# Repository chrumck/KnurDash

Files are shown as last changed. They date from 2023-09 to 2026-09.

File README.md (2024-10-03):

# KnurDash - Racing Data Logger with [RaceChrono](https://racechrono.com/) Integration

<p align="center">
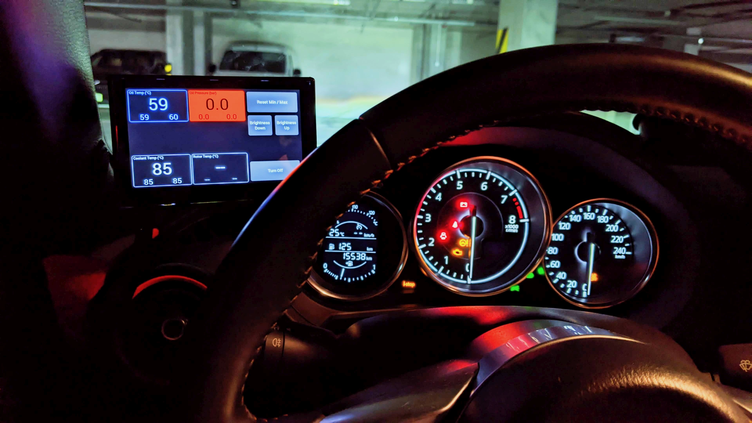
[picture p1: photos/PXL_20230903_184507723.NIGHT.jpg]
    
</p>

## Description

A racing logger for an ND2 Mazda MX-5, integrating wide ranging functionality into one unit:

- Reading analog sensors (oil pressure and temperature, rotor temperature)
- Reading CANBUS data (coolant and intake temperature, RPM, etc.)
- Displaying data in a clear and aesthetically pleasing way
- Making data available via Bluetooth as [RaceChrono DIY BLE device](https://github.com/aollin/racechrono-ble-diy-device)

---

## Technical Details

The system has two main components, the display unit and the sensor unit. The communication between the two is executed through I2C protocol (1.2m cable is pushing it though. With careful cable prep I still get ~0.5% error rate on comms.). The display unit is made of a Raspberry Pi 4B board and a [4.3 inch touchscreen](https://www.waveshare.com/4.3inch-dsi-lcd-with-case.htm). The sensor unit houses a [5V power supply](https://www.pololu.com/product/3782/specs), two [4-channel ADC's](https://www.dfrobot.com/index.php?route=product/product&product_id=1182&search=DFR0316), a [motion tracking device](https://www.dfrobot.com/index.php?route=product/product&product_id=880), and a [Longan Labs I2C CAN Controller](https://docs.longan-labs.cc/1030017/) with a [custom firmware](https://github.com/chrumck/I2C_CAN_Firmware) built specifically for this project.

Additionally, the sensor unit contains circuitry [(LTSpice schematic)](./LTSpice/PowerOffCircuit.asc) allowing starting the system when the vehicle's START button is pressed. This has been accomplished by pulling RPI's GLOBAL_EN to ground when RPI is off. When RPI is running and [3.3V is on](https://www.raspberrypi.com/documentation/computers/raspberry-pi.html#POWER_OFF_ON_HALT), the starting circuit is disabled to prevent hard resets while RPI system and the OS is running.

Bluetooth communication was implemented using the [bluez_inc](https://github.com/weliem/bluez_inc) library (kudos to [weliem](https://github.com/weliem) for making my life easier!). The system implements the [RaceChrono BLE DIY](https://github.com/aollin/racechrono-ble-diy-device) protocol. The system works as a pass-through for selected CAN frames. Additionally, all analog data collected by the unit is exposed as an additional CAN frame and made available to RaceChrono for logging.

The display unit has a buzzer installed. The buzzer is turned on when the oil pressure drops below a certain threshold and the RPM is above idling.

The rotor temperature is measured with an industrial grade 0~1000 degC infrared pyrometer with a 4-20mA output.

As of 2023-09-04, the system is installed in the car and in initial testing . The transmission, differential, and rotor temperature sensors were not installed yet, but coming soon!

Future development:

- Read motion tracking data from the already installed unit and expose it to RaceChrono
- Add a [differential GPS](https://www.sparkfun.com/products/15136) board

---

## Pictures

### Display Unit

 <p align="center">
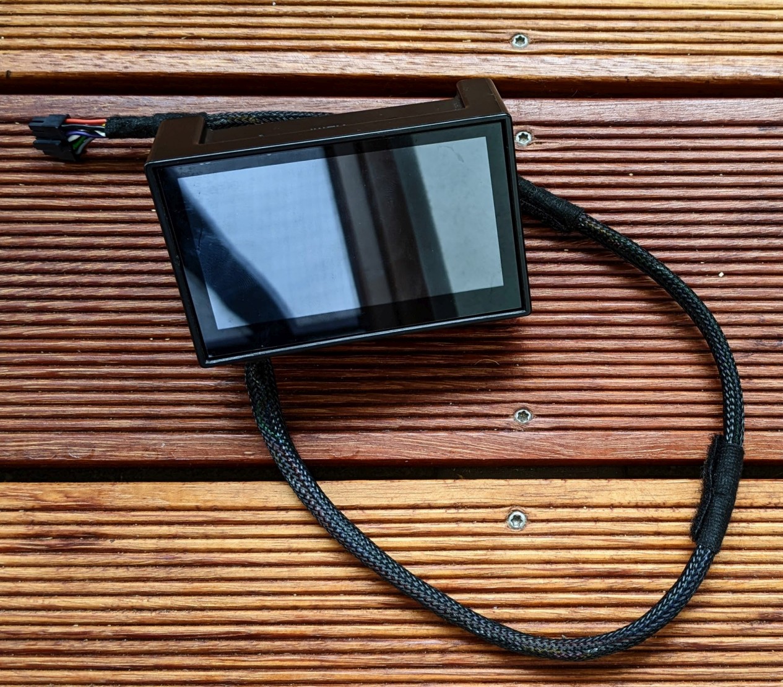
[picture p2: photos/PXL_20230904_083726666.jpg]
    
 
</p>
 <p align="center">
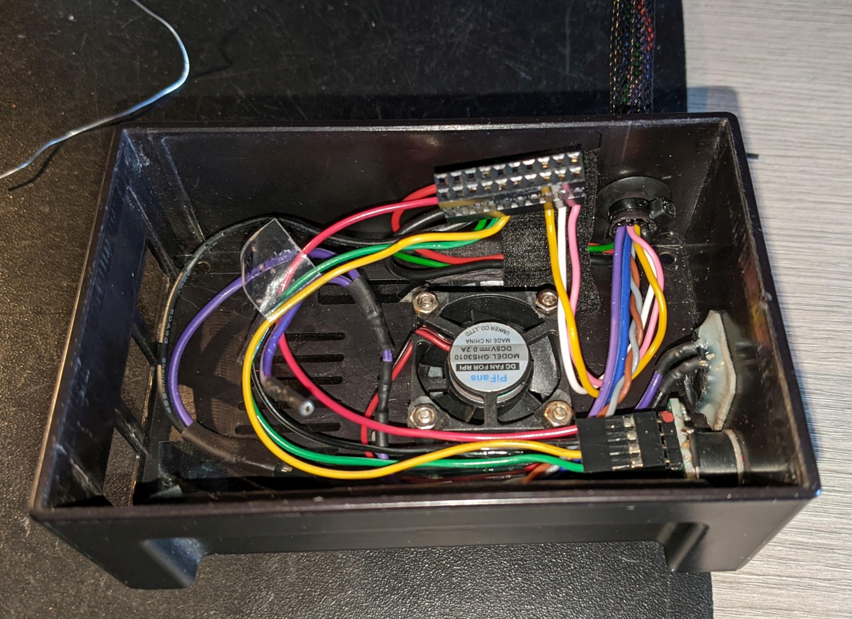
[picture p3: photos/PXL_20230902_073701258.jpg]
    
 </p>

### Sensor Unit

<p align="center">
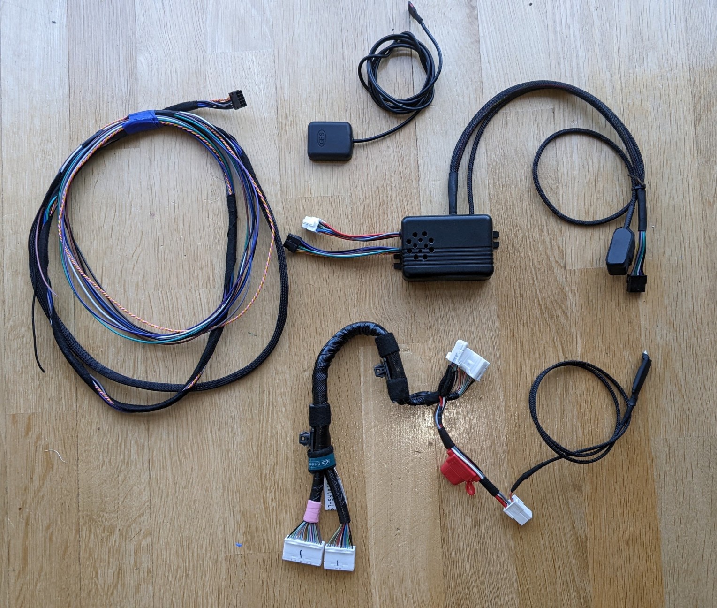
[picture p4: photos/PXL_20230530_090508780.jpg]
    
 </p>

<p align="center">
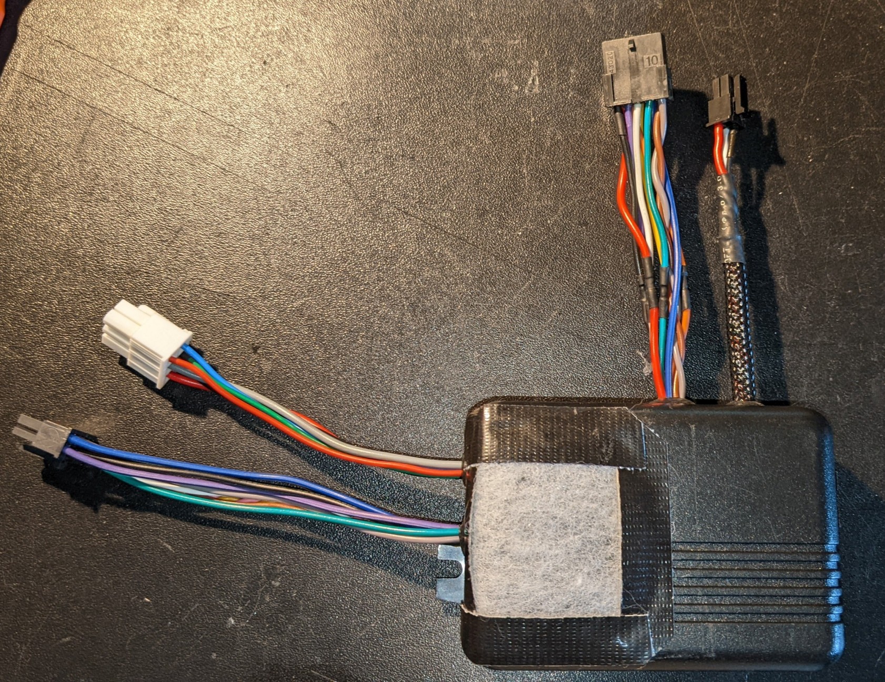
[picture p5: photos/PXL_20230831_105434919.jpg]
    
 </p>

 <p align="center">
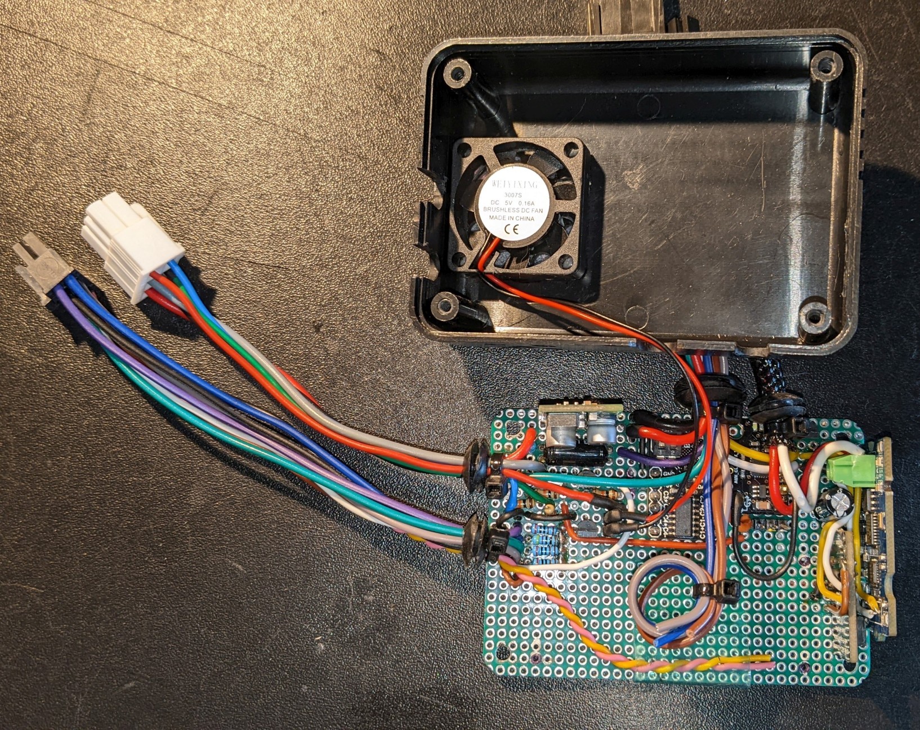
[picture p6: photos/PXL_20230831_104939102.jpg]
    
 </p>

  <p align="center">
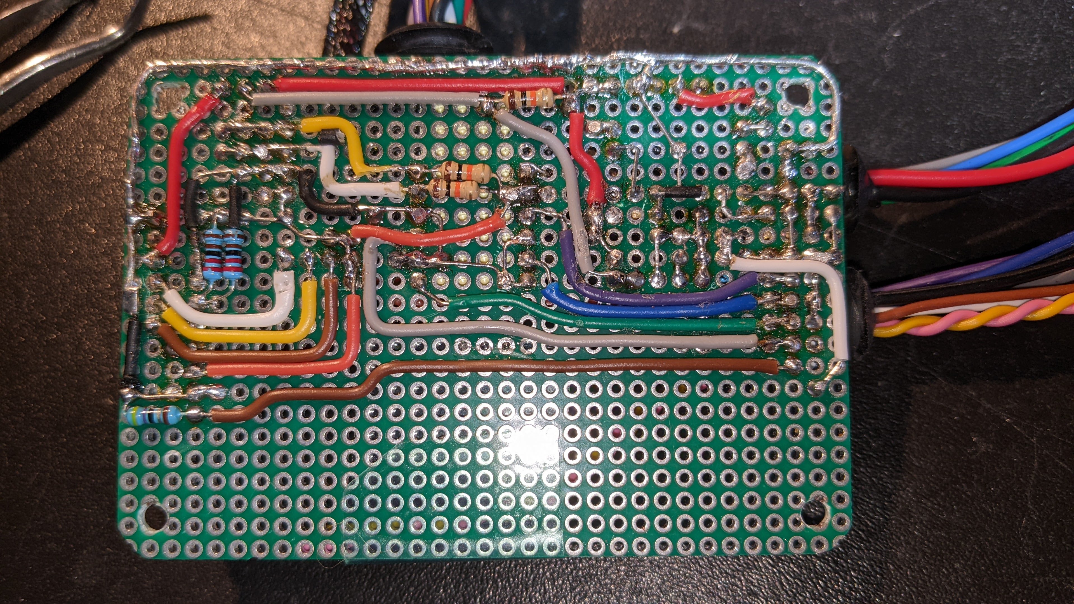
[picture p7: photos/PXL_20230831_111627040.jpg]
    
 </p>

### Sensors

 <p align="center">
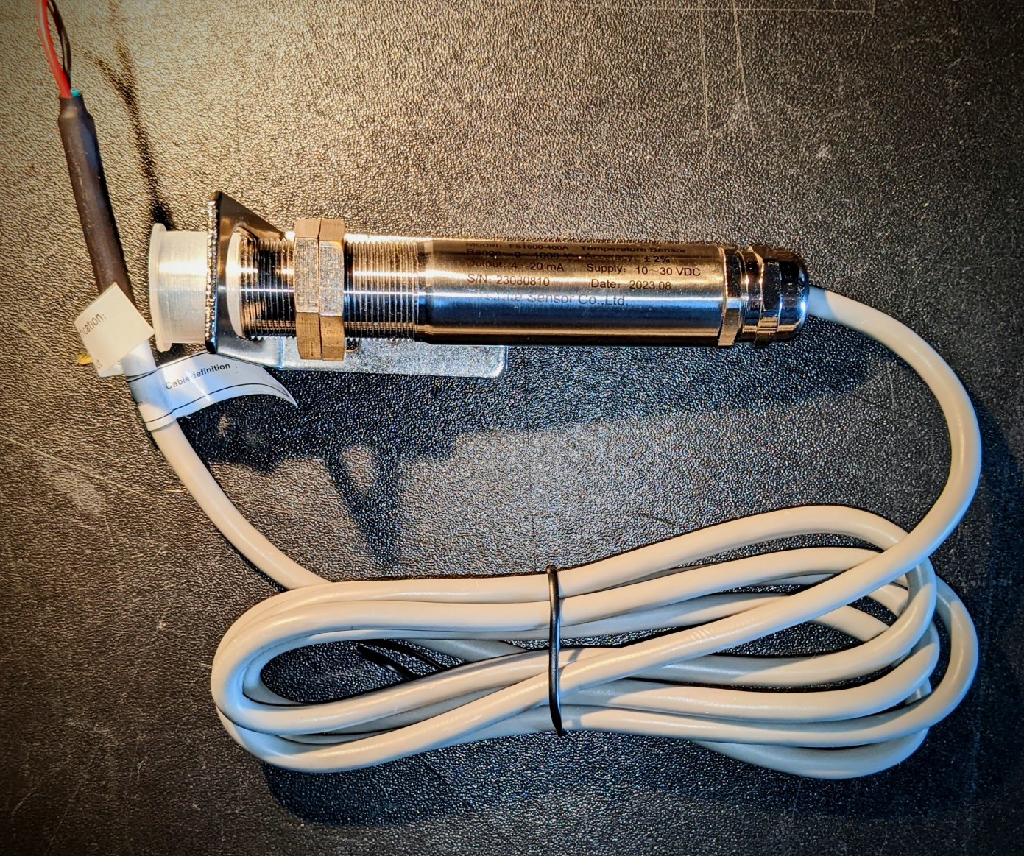
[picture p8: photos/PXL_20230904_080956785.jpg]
    
 </p>

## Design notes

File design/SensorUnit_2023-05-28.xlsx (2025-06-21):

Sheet: Calcs
Vref 3V
Vdd | 3.3 | V
Vref 3V | 3 | V
Rstab | 220 | Ohm
I | 1.363636364
P | 0.0004090909091 | W
Sensors
Vin | 3.3 | V
Rref | 20000 | Ohm
Rsensor | 124 | Ohm
Vout | 20.3 | mV | 40.66785927
I
 | Ref | min | max | Imin mA | Imax mA | vmin V | vmax V | vmin mV | vmax mV | Pmax (W) | Rmin | Rmax
Temp | 2000 | 20 | 2500 | 1.63 | 0.73 | 0.03 | 1.83 | 32.67326733 | 1833.333333 | 0.002 | 2020 | 4500 | 0.0009900990099 | 1010
Pressure | 465 | 8 | 200 | 6.98 | 4.96 | 0.06 | 0.99 | 55.81395349 | 992.481203 | 0.016 | 473 | 665 | 0.00422832981 | 236.5 | 0.00521842882 | 191.62856
Brake Caliper T | 20000 | 122 | 32000 | 0.16 | 0.06 | 0.02 | 2.03 | 20.0079515 | 2030.769231 | 0.0002094230769 | 20122 | 52000 | 9.939369844e-05 | 10061
Vsensor | 162 | mV |  | Capacitor discharge speed
Vref | 3138 | mV |  | uF | ohm | v1 | v0 | t | tms | tus
Rref | 2000 | Ohm |  | 470 | 500 | 3.3 | 3.31
I | 1.569 | mA |  | 0.00047 | 500 | 3.3 | 3.31 | -0.0007110444154 | -0.7110444154 | -711.0444154
Rsensor | 103.250478 | Ohm
Tsensor | 100.1 | degC
Press | 2.7 | bar
IR Rotor Temp Sensor
I_mA | Rref_Ohm | mV
4 | 47 | 188
20 | 47 | 940
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

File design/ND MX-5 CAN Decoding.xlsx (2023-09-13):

Notes: * All bytes are big-endian. |  |  | verified on 2019 ND2 AE
 |  |  | A | B | C | D | E | F | G | H
 | Offset |  | 0 | 1 | 2 | 3 | 4 | 5 | 6 | 7
BUS | CAN ID (HEX) | CAN ID (DEC) | Byte 1 | Byte 2 | Byte 3 | Byte 4 | Byte 5 | Byte 6 | Byte 7 | Byte 8
HS CAN | 202 | 514 | RPM Scaling: 0.25 |  | VehicleSpeed KPH Scaling: 0.01 |  | Throttle % Scaling: 0.4
HS CAN | 165 | 357 |  |  | Clutch_Neutral Neutral: 22 (dec) Clutch-in: 25 (dec) Clutch-out: 23 (dec) |  |  |  | CurrentGear Neutral/1st: 19 (dec) 2nd: 11(dec) 3rd: 7 (dec) 4th: 6 (dec) 5th: 5 (dec)
HS CAN | 240 | 576 | Steering Torque [unitless] offset: -32512, scaling: 1
HS CAN | 78 | 120 |  |  |  | BrakePressure [unitless] Scaling: 1 Offset: -152 starting bit: 28, length 12
HS CAN | 215 | 533 | Wheel1_Speed KPH Scale: 0.01, Offset: -100 |  | Wheel2_Speed KPH Scale: 0.01, Offset: -100 |  | Wheel3_Speed KPH Scale: 0.01, Offset: -100 |  | Wheel4_Speed KPH Scale: 0.01, Offset: -100
HS CAN | 86 | 134 | Steering scaling: -0.0228, offset: 365
HS CAN | 420 | 1056 | EngCoolantTemp offset: -40
HS CAN | 4FA | 1274 |  |  |  |  | IntakeAirTemp C offset: -40
CAN mapping for Auto Sport Labs RaceCapture
 |  |  | Download link for RaceCaptureSettings (https://drive.google.com/open?id=15iy2YZ649EJ6RIQSPAJwfBqKBYgafXnz) |  |  |  | https://github.com/timurrrr/RaceChronoDiyBleDevice/blob/master/can_db/mazda_mx5_nd.md

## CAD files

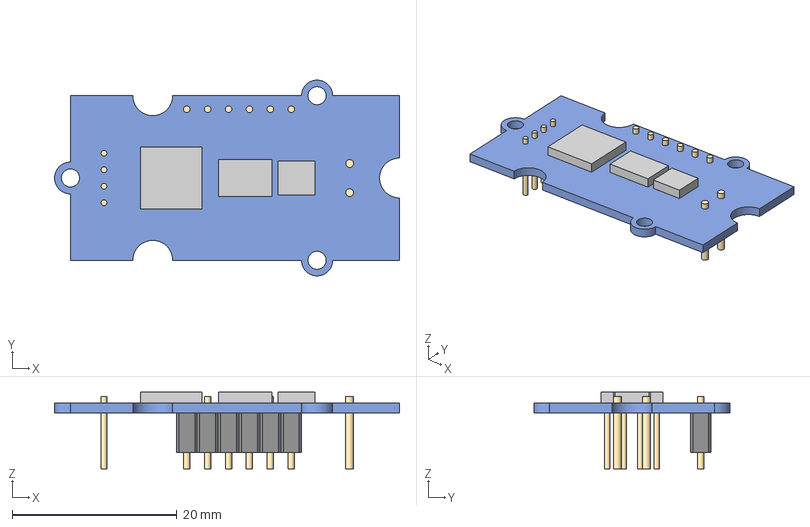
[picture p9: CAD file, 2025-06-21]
KiCAD/Longan_I2C_CAN/Longan_I2C_Can.step
41.9 x 23.8 x 9.30 mm
board
pins
chips

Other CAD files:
KiCAD/Longan_I2C_CAN/Longan_I2C_CAN.dxf
design/SensorUnit_2023-03-23.skp

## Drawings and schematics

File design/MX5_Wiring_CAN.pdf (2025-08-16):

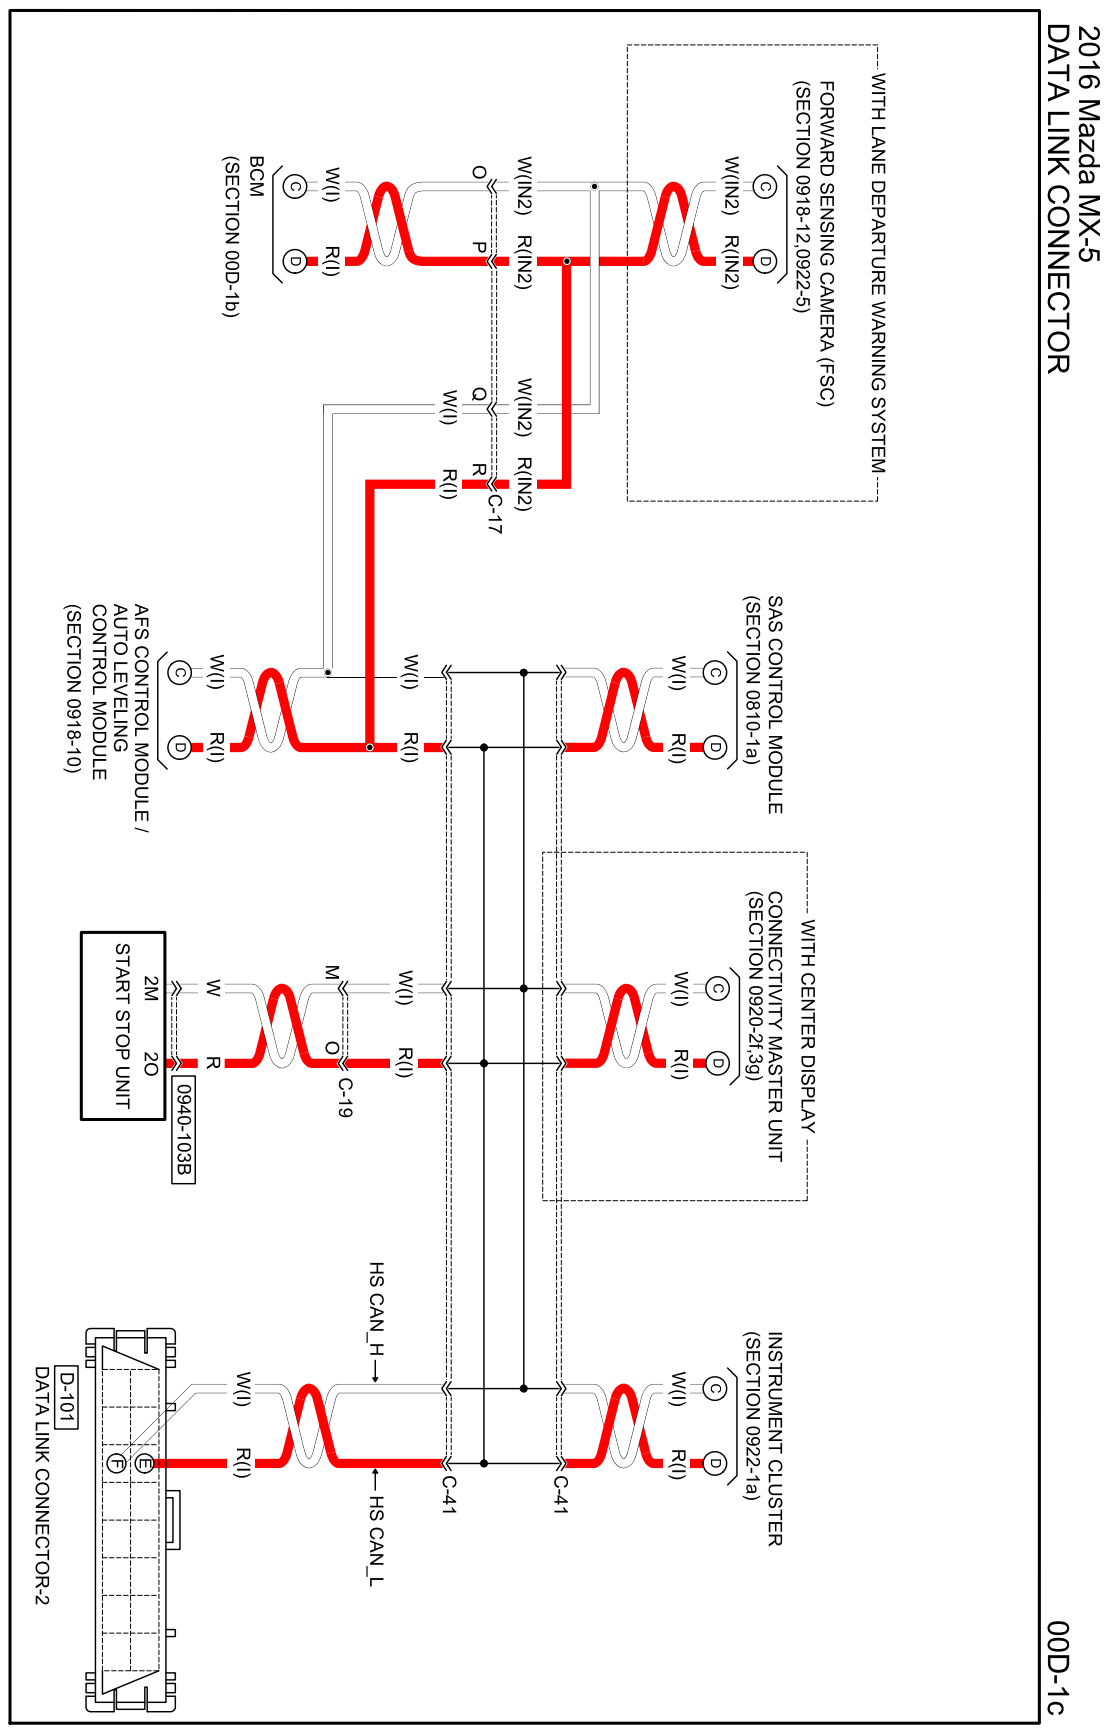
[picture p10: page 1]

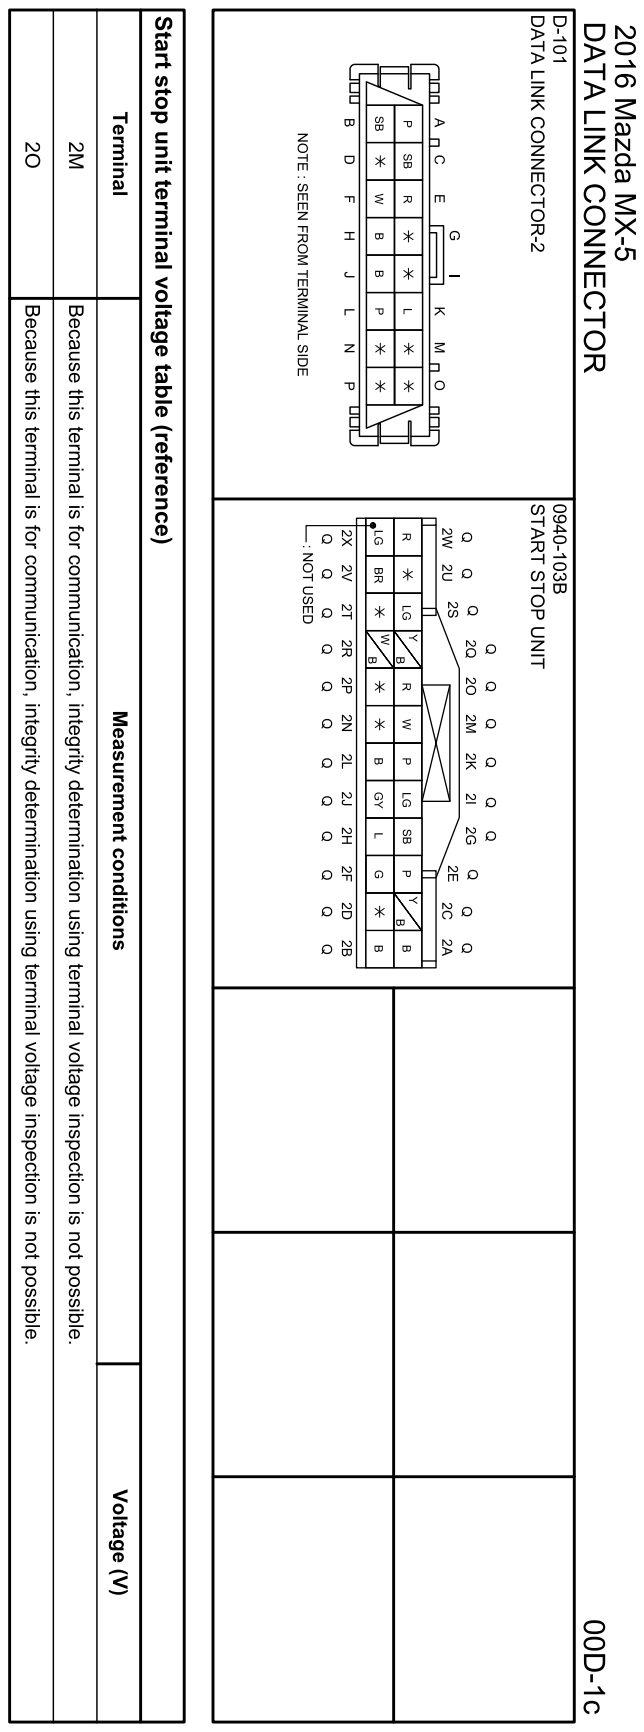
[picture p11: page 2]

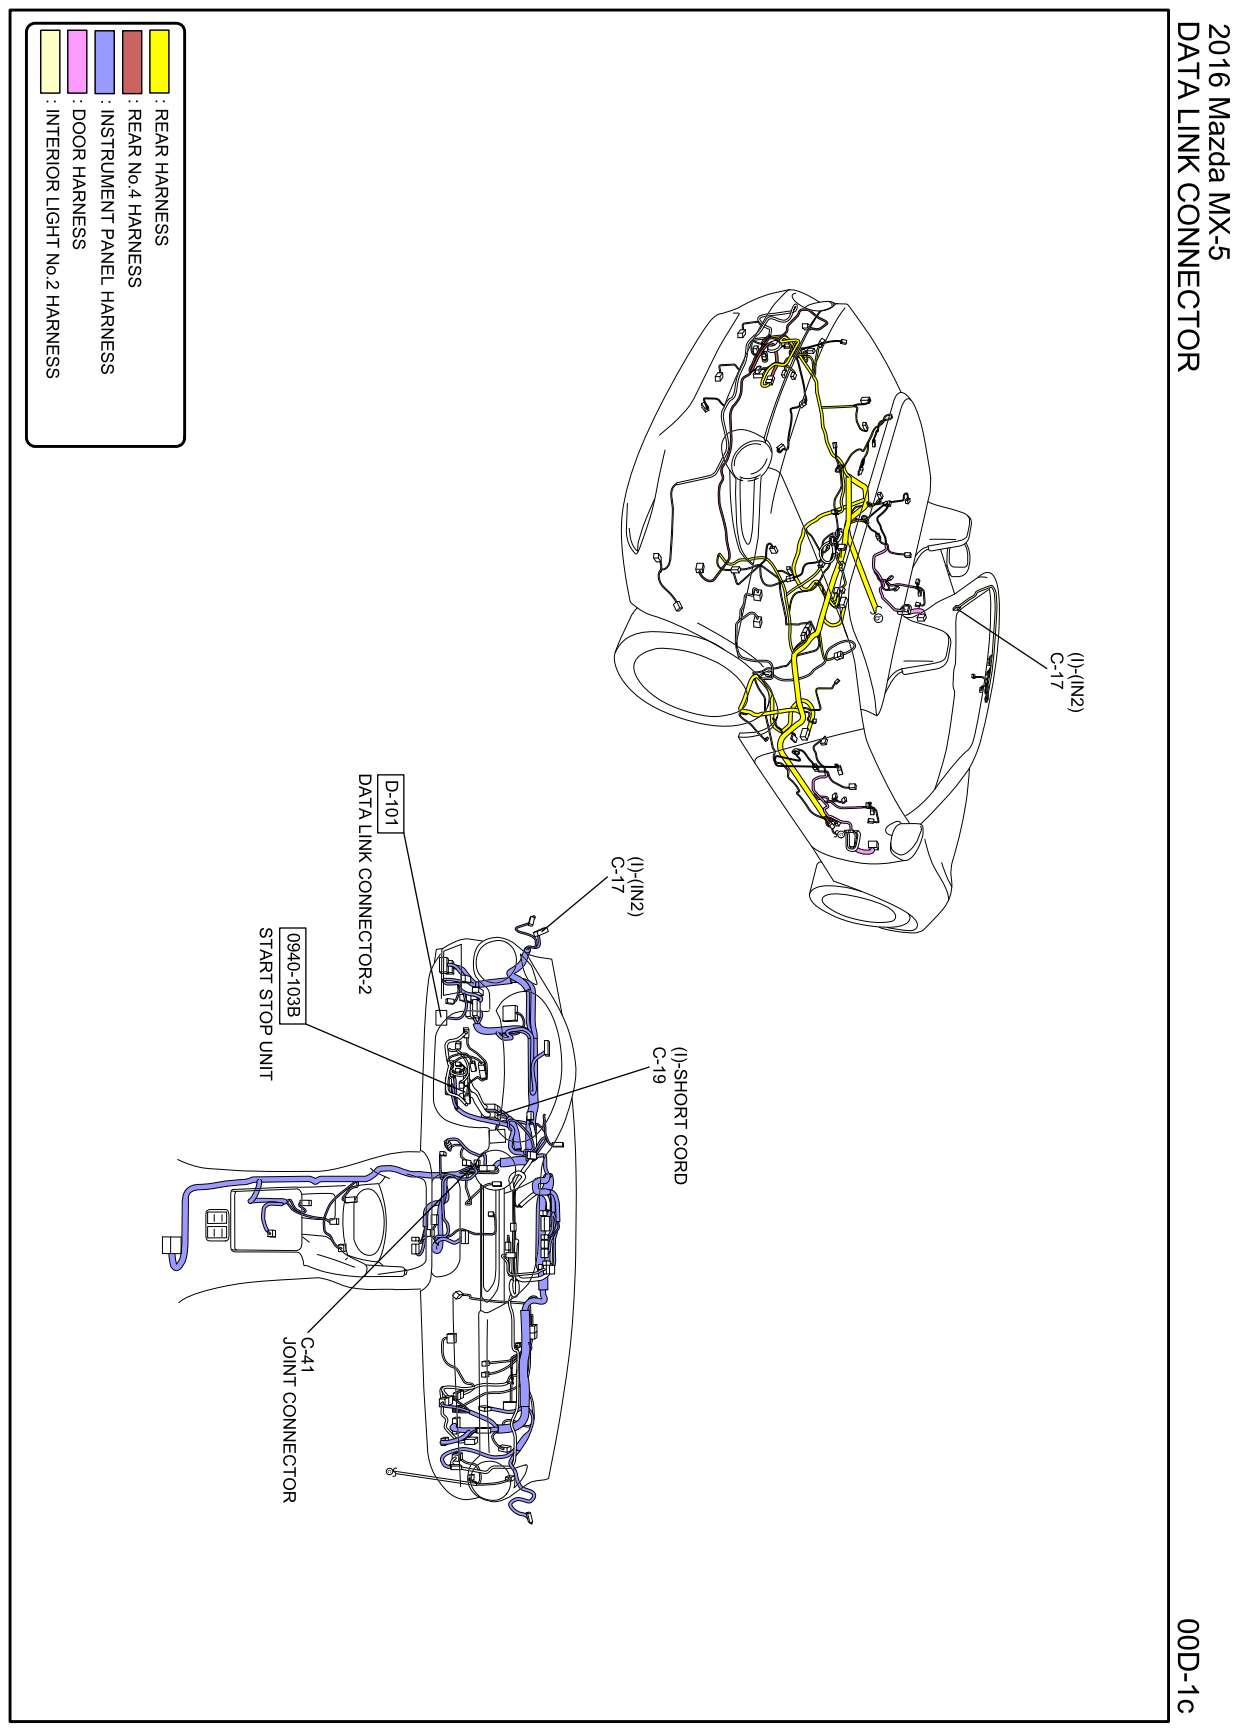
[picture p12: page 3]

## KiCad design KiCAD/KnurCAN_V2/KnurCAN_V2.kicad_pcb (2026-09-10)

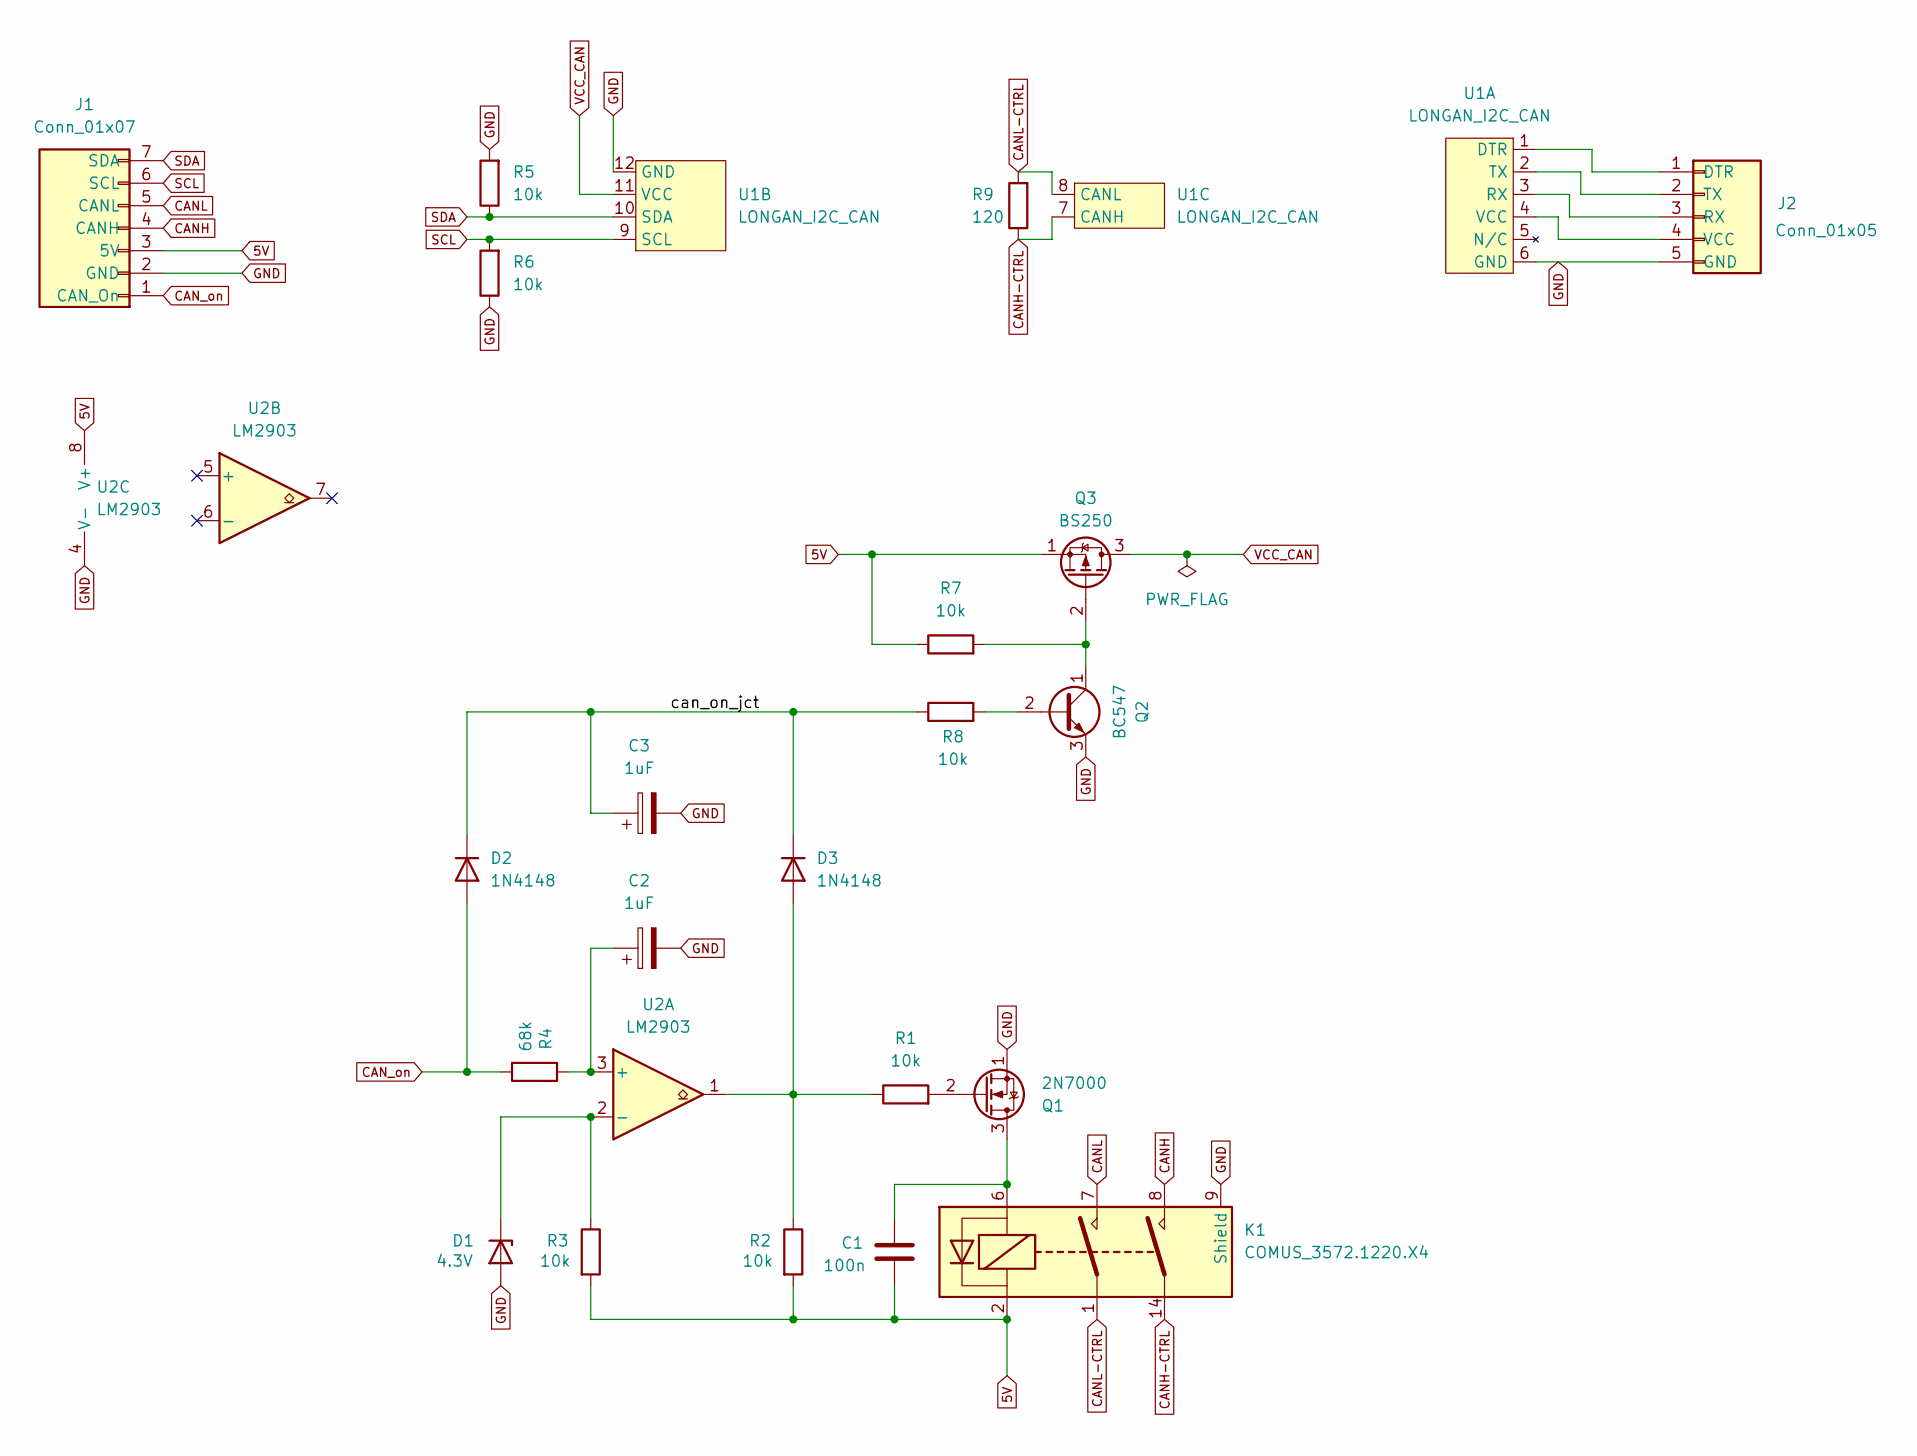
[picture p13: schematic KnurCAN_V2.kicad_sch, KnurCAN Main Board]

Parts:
C1: 100n; C_Disc_D3.8mm_W2.6mm_P2.50mm
C2, C3: 1uF; CP_Radial_D5.0mm_P2.50mm
D1: 4.3V; D_DO-35_SOD27_P7.62mm_Horizontal
D2, D3: 1N4148; D_DO-35_SOD27_P7.62mm_Horizontal
J1: Conn_01x07; SolderWire-1x07-d1.5
J2: Conn_01x05; PinHeader_1x05_P2.54mm_Vertical
K1: COMUS_3572.1220.X4; Relay_COMUS_DIP
Q1: 2N7000; TO-92_Inline_Wide
Q2: BC547; TO-92_Inline_Wide
Q3: BS250; TO-92_Inline_Wide
R1, R2, R3, R5, R6, R7, R8: 10k; R_Axial_DIN0207_L6.3mm_D2.5mm_P7.62mm_Horizontal
R4: 68k; R_Axial_DIN0207_L6.3mm_D2.5mm_P7.62mm_Horizontal
R9: 120; R_Axial_DIN0207_L6.3mm_D2.5mm_P7.62mm_Horizontal
U1: LONGAN_I2C_CAN; Longan_I2C_CAN
U2: LM2903; DIP-8_W7.62mm

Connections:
5V: C1.2, J1.3 (5V), K1.2, Q3.1 (S), R2.2, R3.2, R7.1, U2.8 (V+)
/can_on_jct: C3.1, D2.1 (K), D3.1 (K), R8.1
CANH: J1.4 (CANH), K1.8
CANH-CTRL: K1.14, R9.1, U1.7 (CANH)
CANL: J1.5 (CANL), K1.7
CANL-CTRL: K1.1, R9.2, U1.8 (CANL)
CAN_on: D2.2 (A), J1.1 (CAN_On), R4.2
GND: C2.2, C3.2, D1.2 (A), J1.2 (GND), J2.5 (GND), K1.9 (Shield), Q1.1 (S), Q2.3 (E), R5.2, R6.1, U1.6 (GND), U1.12 (GND), U2.4 (V-)
unnamed: D1.1 (K), R3.1, U2.2 (-)
unnamed: D3.2 (A), R1.1, R2.1, U2.1
unnamed: J2.1 (DTR), U1.1 (DTR)
unnamed: J2.3 (RX), U1.3 (RX)
unnamed: J2.2 (TX), U1.2 (TX)
unnamed: J2.4 (VCC), U1.4 (VCC)
unnamed: C1.1, K1.6, Q1.3 (D)
unnamed: Q1.2 (G), R1.2
unnamed: Q2.2 (B), R8.2
unnamed: Q2.1 (C), Q3.2 (G), R7.2
unnamed: C2.1, R4.1, U2.3 (+)
SCL: J1.6 (SCL), R6.2, U1.9 (SCL)
SDA: J1.7 (SDA), R5.1, U1.10 (SDA)
VCC_CAN: Q3.3 (D), U1.11 (VCC)

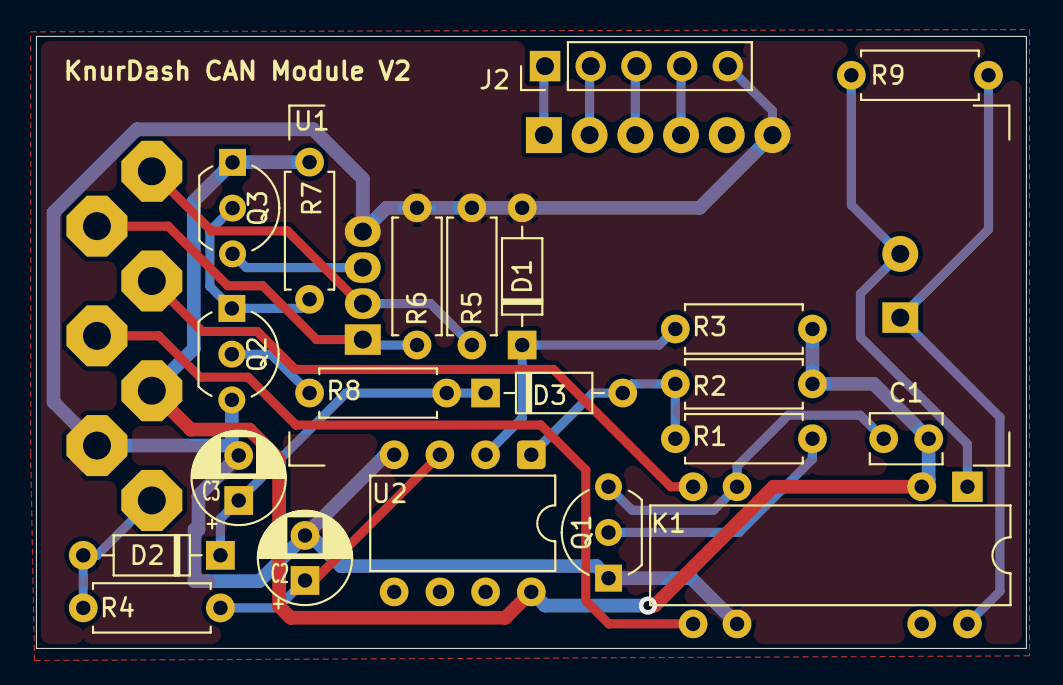
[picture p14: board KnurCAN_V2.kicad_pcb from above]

Board: 2 copper layers, 55.0 x 34.0 mm, 23 parts (0 on the bottom side), 22 nets.

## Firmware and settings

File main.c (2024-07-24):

#define G_LOG_USE_STRUCTURED

#include <gtk/gtk.h>
#include <signal.h>
#include <glib-unix.h>

#include "dataContracts.h"
#include "helpers.c"
#include "appData.c"
#include "ui.c"
#include "sensorWorker.c"
#include "canBusWorker.c"
#include "bluetoothWorker.c"
#include "systemWorker.c"

#define FILE_PATH_LENGTH (PATH_MAX + 1)

int main(int argc, char* argv[])
{
    appData.startupTimestamp = g_get_monotonic_time();

    gtk_init(&argc, &argv);

    char exeFilePath[FILE_PATH_LENGTH];
    readlink("/proc/self/exe", exeFilePath, FILE_PATH_LENGTH);

    char cssFilePath[FILE_PATH_LENGTH];
    sprintf(cssFilePath, "%s%s", exeFilePath, ".css");

    GError* error = NULL;
    GtkCssProvider* cssProvider = gtk_css_provider_new();
    gtk_css_provider_load_from_path(cssProvider, cssFilePath, &error);

    if (error != NULL) logErrorAndKill("Error loading file: %s\n", error->message);

    GdkScreen* screen = gdk_screen_get_default();
    gtk_style_context_add_provider_for_screen(screen, GTK_STYLE_PROVIDER(cssProvider), GTK_STYLE_PROVIDER_PRIORITY_USER);

    char uiFilePath[FILE_PATH_LENGTH];
    sprintf(uiFilePath, "%s%s", exeFilePath, ".ui");

    GtkBuilder* builder = gtk_builder_new();
    gtk_builder_add_from_file(builder, uiFilePath, &error);
    if (error != NULL) logErrorAndKill("Error loading file: %s\n", error->message);

    GObject* window = gtk_builder_get_object(builder, "window");

    gtk_window_fullscreen(GTK_WINDOW(window));

    appData.builder = builder;

    GThread* sensorWorker = g_thread_new("readAnalogSensors", sensorWorkerLoop, NULL);
    GThread* canBusWorker = g_thread_new("canBusWorker", canBusWorkerLoop, NULL);
    GThread* bluetoothWorker = g_thread_new("bluetoothWorker", bluetoothWorkerLoop, NULL);
    GThread* systemWorker = g_thread_new("systemWorker", systemWorkerLoop, NULL);

    g_unix_signal_add(SIGINT, shutDown, GUINT_TO_POINTER(AppShutdown));
    g_unix_signal_add(SIGTERM, shutDown, GUINT_TO_POINTER(AppShutdown));

    g_signal_connect(window, "destroy", G_CALLBACK(shutDown), GUINT_TO_POINTER(AppShutdown));

    GObject* button = gtk_builder_get_object(builder, "resetMinMax");
    g_signal_connect(button, "clicked", G_CALLBACK(requestMinMaxReset), NULL);

    button = gtk_builder_get_object(builder, "brightnessDown");
    g_signal_connect(button, "clicked", G_CALLBACK(setBrightnessDown), NULL);

    button = gtk_builder_get_object(builder, "brightnessUp");
    g_signal_connect(button, "clicked", G_CALLBACK(setBrightnessUp), NULL);

    button = gtk_builder_get_object(builder, "turnOff");
    g_signal_connect(button, "clicked", G_CALLBACK(buttonShutDown), NULL);

    gtk_main();

    g_thread_join(sensorWorker);
    g_thread_join(canBusWorker);
    g_thread_join(bluetoothWorker);
    g_thread_join(systemWorker);

    g_message("KnurDash app terminated");

    return 0;
}

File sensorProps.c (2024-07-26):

#pragma once

#include <gtk/gtk.h>
#include <math.h>

#include "dataContracts.h"

#define ADC_DEFAULT_CONFIG 0x10
#define ADC_BIT_RESOLUTION 12

#define VDD_DEFAULT 3350
#define VDD_ADC 1
#define VDD_CHANNEL 3

#define TRANS_TEMP_ADC 0
#define TRANS_TEMP_CHANNEL 0
#define DIFF_TEMP_ADC 0
#define DIFF_TEMP_CHANNEL 1
#define OIL_TEMP_ADC 0
#define OIL_TEMP_CHANNEL 2
#define OIL_PRESS_ADC 0
#define OIL_PRESS_CHANNEL 3

#define ROTOR_TEMP_ADC 1
#define ROTOR_TEMP_CHANNEL 1
#define CALIPER_TEMP_ADC 1
#define CALIPER_TEMP_CHANNEL 2

#define TEMP_SENSOR_RAW_MIN 30
#define TEMP_SENSOR_RAW_MAX 2030

#define ROTOR_TEMP_SENSOR_RAW_MIN 226 // 50 degC
#define ROTOR_TEMP_SENSOR_RAW_MAX 1000

#define CALIPER_TEMP_SENSOR_RAW_MIN 15
#define CALIPER_TEMP_SENSOR_RAW_MAX 2040

#define PRESS_SENSOR_RAW_MIN 30
#define PRESS_SENSOR_RAW_MAX 1000

#define VDD_RAW_MIN 1550
#define VDD_RAW_MAX 1750

#define TEMP_A 276.3
#define TEMP_B -39.95
#define TEMP_C 0.09136

#define CALIPER_TEMP_A 761.89
#define CALIPER_TEMP_B -137.70
#define CALIPER_TEMP_C 9.5068
#define CALIPER_TEMP_D -0.27223

#define PRESS_A -0.2967
#define PRESS_B 0.02529
#define PRESS_C 0.0000350

#define ROTOR_TEMP_A -250
#define ROTOR_TEMP_B 62.5

gdouble convertTemp(gint32 sensorV, gint32 driveV, gint32 refR) {
    const gdouble sensorR = (gdouble)sensorV * refR / (driveV - sensorV);
    const gdouble logSensorR = log(sensorR);
    return TEMP_A + (TEMP_B * logSensorR) + (TEMP_C * pow(logSensorR, 3));
}

gdouble convertOilPress(gint32 sensorV, gint32 driveV, gint32 refR) {
    const gdouble sensorR = (gdouble)sensorV * refR / (driveV - sensorV);
    const gdouble value = PRESS_A + (PRESS_B * sensorR) + (PRESS_C * pow(sensorR, 2));
    return value < 0 ? 0 : value;
}

gdouble convertVdd(gint32 sensorV, gint32 driveV, gint32 refR) {
    return sensorV * 2;
}

gdouble convertRotorTemp(gint32 sensorV, gint32 driveV, gint32 refR) {
    const gdouble sensorI = (gdouble)sensorV / ((gdouble)refR / 10);
    const double value = ROTOR_TEMP_A + (ROTOR_TEMP_B * sensorI);
    return value < 0 ? 0 : value;
}

gdouble convertCaliperTemp(gint32 sensorV, gint32 driveV, gint32 refR) {
    const gdouble sensorR = (gdouble)sensorV * refR / (driveV - sensorV);
    const gdouble logSensorR = log(sensorR);
    return CALIPER_TEMP_A + CALIPER_TEMP_B * logSensorR + CALIPER_TEMP_C * pow(logSensorR, 2) + CALIPER_TEMP_D * pow(logSensorR, 3);
}

const AdcSensor adcSensors[ADC_COUNT][ADC_CHANNEL_COUNT] = {
    {
        {
            .base = {
                .labelId = "transTemp", .frameId = "transTempFrame", .labelMinId = "transTempMin", .labelMaxId = "transTempMax",
                .alertLow = -25, .warningLow = -25, .notifyLow = -25,
                .notifyHigh = 130, .warningHigh = 130, .alertHigh = 140,
                .rawMin = TEMP_SENSOR_RAW_MIN, .rawMax = TEMP_SENSOR_RAW_MAX,
                .defaultValue = 10.0, .format = "%.0f" , .precision = 0.3,
            },
             .pga = AdcPgaX1, .refR = 2012, .convert = convertTemp,
        },
        {
            .base = {
                .labelId = "diffTemp", .frameId = "diffTempFrame", .labelMinId = "diffTempMin", .labelMaxId = "diffTempMax",
                .alertLow = -25, .warningLow = -25, .notifyLow = -25,
                .notifyHigh = 135, .warningHigh = 135, .alertHigh = 150,
                .rawMin = TEMP_SENSOR_RAW_MIN, .rawMax = TEMP_SENSOR_RAW_MAX,
                .defaultValue = 10.0, .format = "%.0f" , .precision = 0.3,
            },
            .pga = AdcPgaX1, .refR = 2006, .convert = convertTemp,
        },
        {
            .base = {
                .labelId = "oilTemp", .frameId = "oilTempFrame", .labelMinId = "oilTempMin", .labelMaxId = "oilTempMax",
                .alertLow = -30, .warningLow = -30, .notifyLow = 80,
                .notifyHigh = 125, .warningHigh = 125, .alertHigh = 135,
                .rawMin = TEMP_SENSOR_RAW_MIN, .rawMax = TEMP_SENSOR_RAW_MAX,
                .defaultValue = 10.0, .format = "%.0f" , .precision = 0.3,
            },
            .pga = AdcPgaX1, .refR = 1992, .convert = convertTemp,
        },
        {
            .base = {
                .labelId = "oilPress", .frameId = "oilPressFrame", .labelMinId = "oilPressMin", .labelMaxId = "oilPressMax",
                .alertLow = 0.7, .warningLow = 1.0, .notifyLow = 1.0,
                .notifyHigh = 5.5, .warningHigh = 5.5, .alertHigh = 6.0,
                .rawMin = PRESS_SENSOR_RAW_MIN, .rawMax = PRESS_SENSOR_RAW_MAX,
                .defaultValue = 0.0, .format = "%.1f" , .precision = 0.05,
            },
            .pga = AdcPgaX1, .refR = 465, .convert = convertOilPress,
        },
    },
    {
        {},
        {
            .base = {
                .labelId = "rotorTemp", .frameId = "rotorTempFrame", .labelMinId = "rotorTempMin", .labelMaxId = "rotorTempMax",
                .alertLow = -25, .warningLow = -25, .notifyLow = -25,
                .notifyHigh = 800, .warningHigh = 800, .alertHigh = 900,
                .rawMin = ROTOR_TEMP_SENSOR_RAW_MIN, .rawMax = ROTOR_TEMP_SENSOR_RAW_MAX,
                .defaultValue = 10.0, .format = "%.0f" , .precision = 5,
            },
            .pga = AdcPgaX2, .refR = 468, .convert = convertRotorTemp,
        },
        {
            .base = {
                .labelId = "caliperTemp", .frameId = "caliperTempFrame", .labelMinId = "caliperTempMin", .labelMaxId = "caliperTempMax",
                .alertLow = -25, .warningLow = -25, .notifyLow = -25,
                .notifyHigh = 150, .warningHigh = 150, .alertHigh = 200,
                .rawMin = CALIPER_TEMP_SENSOR_RAW_MIN, .rawMax = CALIPER_TEMP_SENSOR_RAW_MAX,
                .defaultValue = 10.0, .format = "%.0f" , .precision = 0.5,
            },
            .pga = AdcPgaAdaptive, .refR = 20000, .convert = convertCaliperTemp,
        },
        {
            .base = { // reference voltage for sensors, not shown in UI
                .alertLow = VDD_RAW_MIN * 2, .warningLow = VDD_RAW_MIN * 2, .notifyLow = VDD_RAW_MIN * 2,
                .notifyHigh = VDD_RAW_MAX * 2, .warningHigh = VDD_RAW_MAX * 2, .alertHigh = VDD_RAW_MAX * 2,
                .rawMin = VDD_RAW_MIN, .rawMax = VDD_RAW_MAX,
                .defaultValue = VDD_DEFAULT, .format = "%.0f" , .precision = 2,
            },
            .pga = AdcPgaX1, .refR = 0, .convert = convertVdd,
        },
    }
};

gdouble getAdcSensorValue(gint adc, gint channel) {
    SensorReading* reading = &(appData.sensors.adcReadings)[adc][channel];
    const AdcSensor* sensor = &adcSensors[adc][channel];

    return reading->errorCount < SENSOR_WARNING_ERROR_COUNT ?
        reading->value : sensor->base.defaultValue;
}

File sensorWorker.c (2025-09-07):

#include <gtk/gtk.h>
#include <pigpiod_if2.h>
#include <math.h>

#include "dataContracts.h"
#include "appData.c"
#include "helpers.c"
#include "sensorProps.c"
#include "canBusProps.c"
#include "ui.c"

#define SENSOR_WORKER_LOOP_INTERVAL_US 25000
#define ADC_SWITCH_CHANNEL_SLEEP_US 5000

#define FAULTY_READING_LABEL "--"
#define ADC_READING_DEADBAND 10

#define ADC0_I2C_ADDRESS 0x6a
#define ADC1_I2C_ADDRESS 0x6c
#define ADC_CHANNEL_MASK 0x60

#define getAdcChannelValue(config) (((config) & ADC_CHANNEL_MASK) >> 5)
#define getAdcChannelBits(channel) (((channel) << 5) & ADC_CHANNEL_MASK)

//-------------------------------------------------------------------------------------------------------------

void setLabel(GtkLabel* label, const char* format, gdouble reading) {
    if (label == NULL) return;
    gpointer data = malloc(sizeof(SetLabelArgs));
    SetLabelArgs* args = (SetLabelArgs*)data;
    args->label = label;
    sprintf(args->value, format, reading);
    g_idle_add(setLabelText, data);
}

void setFrame(GtkFrame* frame, const SensorState state) {
    if (frame == NULL) return;
    gpointer data = malloc(sizeof(SetFrameClassArgs));
    SetFrameClassArgs* args = (SetFrameClassArgs*)data;
    args->frame = frame;
    args->state = state;
    g_idle_add(setFrameClass, data);
}

void resetReadingsValues() {
    for (int i = 0; i < ADC_COUNT; i++) {
        for (int j = 0; j < ADC_CHANNEL_COUNT; j++) {
            const SensorBase* sensor = &adcSensors[i][j].base;
            SensorReading* reading = &appData.sensors.adcReadings[i][j];
            reading->value = sensor->defaultValue;
            reading->errorCount = 1;
        }
    }
    for (int i = 0; i < CAN_SENSORS_COUNT; i++) {
        const SensorBase* sensor = &canSensors[i].base;
        SensorReading* reading = &appData.sensors.canReadings[i];
        reading->value = sensor->defaultValue;
        reading->errorCount = 1;
    }
};

void resetReadingsMinMax() {
    for (int i = 0; i < ADC_COUNT; i++) {
        for (int j = 0; j < ADC_CHANNEL_COUNT; j++) {
            appData.sensors.adcReadings[i][j].min = G_MAXDOUBLE;
            appData.sensors.adcReadings[i][j].max = -G_MAXDOUBLE;
        }
    }

    for (int i = 0; i < CAN_SENSORS_COUNT; i++) {
        appData.sensors.canReadings[i].min = G_MAXDOUBLE;
        appData.sensors.canReadings[i].max = -G_MAXDOUBLE;
    }
};

void setSingleSensorWidgets(const SensorBase* sensor, SensorWidgets* widgets) {
    GtkBuilder* builder = appData.builder;
    if (sensor->labelId != NULL) widgets->label = GTK_LABEL(gtk_builder_get_object(builder, sensor->labelId));
    if (sensor->frameId != NULL) widgets->frame = GTK_FRAME(gtk_builder_get_object(builder, sensor->frameId));
    if (sensor->labelMinId != NULL) widgets->labelMin = GTK_LABEL(gtk_builder_get_object(builder, sensor->labelMinId));
    if (sensor->labelMaxId != NULL) widgets->labelMax = GTK_LABEL(gtk_builder_get_object(builder, sensor->labelMaxId));
}

void setWidgets() {
    for (int i = 0; i < ADC_COUNT; i++) {
        for (int j = 0; j < ADC_CHANNEL_COUNT; j++) {
            const SensorBase* sensor = &adcSensors[i][j].base;
            SensorWidgets* widgets = &appData.sensors.adcWidgets[i][j];
            setSingleSensorWidgets(sensor, widgets);
        }
    }
    for (int i = 0; i < CAN_SENSORS_COUNT; i++) {
        const SensorBase* sensor = &canSensors[i].base;
        SensorWidgets* widgets = &appData.sensors.canWidgets[i];
        setSingleSensorWidgets(sensor, widgets);
    }
};

void resetMinMaxLabels() {
    for (int i = 0; i < ADC_COUNT; i++) {
        for (int j = 0; j < ADC_CHANNEL_COUNT; j++) {
            const SensorWidgets* widgets = &appData.sensors.adcWidgets[i][j];
            setLabel(widgets->labelMin, FAULTY_READING_LABEL, 0);
            setLabel(widgets->labelMax, FAULTY_READING_LABEL, 0);
        }
    }
    for (int i = 0; i < CAN_SENSORS_COUNT; i++) {
        const SensorWidgets* widgets = &appData.sensors.canWidgets[i];
        setLabel(widgets->labelMin, FAULTY_READING_LABEL, 0);
        setLabel(widgets->labelMax, FAULTY_READING_LABEL, 0);

    }
};

SensorState getSensorState(const SensorBase* sensor, const gdouble reading) {
    if (reading < sensor->alertLow) return StateAlertLow;
    if (reading < sensor->warningLow) return StateWarningLow;
    if (reading < sensor->notifyLow) return StateNotifyLow;

    if (reading > sensor->alertHigh) return StateAlertHigh;
    if (reading > sensor->warningHigh) return StateWarningHigh;
    if (reading > sensor->notifyHigh) return StateNotifyLow;

    return StateNormal;
}

#define handleSensorReadFault(_allowSomeErrors)\
    sensors->errorCount++;\
    reading->errorCount++;\
    if (!_allowSomeErrors || (reading->errorCount > SENSOR_WARNING_ERROR_COUNT && reading->errorCount < SENSOR_CRITICAL_ERROR_COUNT)) {\
        setLabel(widgets->label, FAULTY_READING_LABEL, 0);\
        setFrame(widgets->frame, StateNormal);\
    }\

void setSensorReadingAndWidgets(
    gdouble value,
    SensorReading* reading,
    const SensorBase* sensor,
    const SensorWidgets* widgets) {

    if (!reading->errorCount &&
        reading->min != G_MAXDOUBLE &&
        reading->max != -G_MAXDOUBLE &&
        value < reading->value + sensor->precision &&
        value > reading->value - sensor->precision
        ) return;

    gboolean wasFaulty = !!reading->errorCount;

    reading->errorCount = 0;
    reading->value = value;

    setLabel(widgets->label, sensor->format, value);

    if (reading->min > value) {
        reading->min = value;
        setLabel(widgets->labelMin, sensor->format, value);
    }

    if (reading->max < value) {
        reading->max = value;
        setLabel(widgets->labelMax, sensor->format, value);
    }

    const SensorState state = getSensorState(sensor, value);
    if (wasFaulty || state != reading->state) {
        reading->state = state;
        setFrame(widgets->frame, state);
    }
}
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

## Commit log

2023-05-15 Added TURN OFF button
2023-05-15 Fix uiFileName weird bug - strange characters
    [main.c]
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2023-05-20 Fixes, add back shutDown logic
    [dataContracts.h, main.c]
2023-05-20 Add buttonShutDown and windowShutDown
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2023-05-20 remove pigpo from cmake; progress work to connect to adc
2023-05-20 2st try to read from adc
2023-05-20 Change to i2c_read_device; maybe fix cmake extension problems
    [dataContracts.h]
2023-05-22 Refactor sensors.c to take new SensorProps
2023-05-22 Oil pressure first test
2023-05-23 More minor fixes and cleanup
    [main.c]
2023-05-23 Add resetting min and max. Other refactor and cleanup
    [dataContracts.h, main.c, sensorProps.c]
2023-05-23 Fix memory leak around SetLabelArgs
    [dataContracts.h]
2023-05-23 Update pressure sensor min voltage
2023-05-24 Refactor code to prep for two ADC's
2023-05-25 Add VDD sensor reading and consume it for other sensors
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2023-05-29 Add design files and photos
    [SensorUnit_2023-03-23.skp, SensorUnit_2023-05-28.xlsx]
2023-05-29 update xls
    [SensorUnit_2023-05-28.xlsx]
2023-06-03 Add thread_join to main function
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2023-06-11 Fix shutdown logic from withing sensor worker
    [main.c]
2023-06-16 Add attempt to power back up if bt adapter not powered
2023-06-17 Add CAN decoding xls
    [ND MX-5 CAN Decoding.xlsx]
2023-07-11 Add dbc for SavvyCAN
    [ND MX-5 CAN Decoding.xlsx]
2023-07-11 Update x202 frame defs
2023-07-11 xlsx update
    [ND MX-5 CAN Decoding.xlsx]
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2023-07-13 Move pi handle init back to sensor worker
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2023-07-13 Add mask and filter setting
2023-07-13 Add can filter/mask messaging and delay in setting
2023-07-14 Add 3 more frame ids
2023-07-15 change g_error to g_warning on CAN setting fails
    [canBusWorker.c]
2023-07-15 Add canBusProps file; move constants there; start working on storing can frames
2023-07-15 Fix bt worker not shutting down properly
    [bluetoothWorker.c]
2023-07-15 Start adding canbus worker loops
2023-07-15 add sensors frame id
2023-07-16 Add workerData.c to canBusWorker
2023-07-16 fix passing i to getFrameFromCAN
    [canBusWorker.c]
2023-07-16 Add buzzer handling to sensorWorker
    [sensorWorker.c]
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2023-07-17 leave buzzer logic on when debugging
    [sensorWorker.c]
2023-07-17 update CAN errors reporting
    [canBusWorker.c]
2023-07-17 fix bug in setMaskOrFilter - delete extra return;
    [canBusWorker.c]
2023-07-17 Make canbus statistics be reported at shutdown
2023-07-18 shorten wait time after write
    [canBusWorker.c]
2023-07-19 Refactor sensor DTO to separate base properties
2023-07-19 Add coolant temp can sensor to sensorWorker
2023-07-19 decrease can buss polling to ~20Hz
2023-07-19 fix testing for valid range in readCanSensor
    [sensorWorker.c]
2023-07-19 update temp sensors min/max values
2023-07-19 Start working on wiring up bluetooth to can and adc
2023-07-20 Add btWasSent reset to getFrameFromCAN
    [canBusWorker.c]
2023-07-20 wire up onCharStartNotify and onCharStopNotify
2023-07-20 Set BT error messages
    [bluetoothWorker.c]
2023-07-21 fix returns in onChartStartNotify and onCharStopNotify
    [bluetoothWorker.c]
2023-07-22 add reading locking on reading update; clean up reading sensor logic
2023-07-22 fix typo in getAdcFrame
    [bluetoothWorker.c]
2023-07-22 add frame state locking in getEngineRpm and getCoolantTemp
2023-07-22 add sensor reading locking in resetReadingsValues
    [sensorWorker.c]
2023-07-22 read adc sensors in reverse order
    [sensorWorker.c]
2023-07-22 fix getAdc frame passing
    [bluetoothWorker.c]
2023-07-23 make sensorWorker set adc can frame
2023-07-23 remove lock from sensor reading
2023-07-23 lock adc can frame before setting default values
2023-07-23 fix ordering of functions in btWorker
    [bluetoothWorker.c]
2023-07-23 fix bug aroung byte array sizing
    [bluetoothWorker.c]
2023-07-23 round temps to nearest degree before creating adc can frame
2023-07-23 tweak bt and canbus shutdown logic
2023-07-23 add disconnecting to bluetooth worker; improve shutdown logic in canBusWorker
2023-07-24 add error rate tracking to sensor readings
    [dataContracts.h, sensorWorker.c]
2023-07-24 Add app shutdown on excessive canbus error rate
    [canBusWorker.c, dataContracts.h, sensorWorker.c]
2023-07-24 fix bug in getting connection state name
    [bluetoothWorker.c]
2023-07-24 fix source removing logic in bluetooth worker
    [bluetoothWorker.c]
2023-07-24 switch to release version
2023-07-24 fix return values of sendCanFrameToBt
    [bluetoothWorker.c]
2023-07-25 fix pressure rounding bug
    [sensorWorker.c]
2023-07-25 clean up buzzer on/off logic
    [sensorWorker.c]
2023-08-29 canbus decoding updates
    [ND MX-5 CAN Decoding.xlsx]
2023-08-29 update CAN frames definitions
    [ND MX-5 CAN Decoding.xlsx]
2023-08-30 working on CAN decoding
    [ND MX-5 CAN Decoding.xlsx]
2023-08-31 Add rotor temp sensor definition
    [SensorUnit_2023-05-28.xlsx]
2023-08-31 updates to sensor calcs
    [SensorUnit_2023-05-28.xlsx]
2023-09-02 Update pinouts
    [SensorUnit_2023-05-28.xlsx]
2023-09-02 Add more delay between filter and mask setting requests
2023-09-02 Add rotor temp reading step to sensor worker; change temp offset to 40degC
2023-09-02 Add rotor temp to ui
2023-09-02 Fix rotor temp calcs
    [sensorProps.c]
2023-09-03 Add startup retry logic to canBusWorker
2023-09-03 add 5 second delay to shutting down due to errors
    [canBusWorker.c, dataContracts.h, main.c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]
2023-09-10 update CAN decoding
    [ND MX-5 CAN Decoding.xlsx]
2023-09-10 can decoding updates
    [ND MX-5 CAN Decoding.xlsx]
2023-09-10 add delay between canbus start retries
2023-09-10 bump pressure precision to 0.05 bar
2023-09-11 add diff and trans temp frames to ui
2023-09-11 update wiring file
    [SensorUnit_2023-05-28.xlsx]
2023-09-12 add fault tolerance of 5 faults to sensorworker
    [dataContracts.h, sensorWorker.c]
2023-09-12 allow more sensor worker logging when error count > 5
    [sensorWorker.c]
2023-09-13 change canbus frame state from receiveFailed to errorCount
    [canBusWorker.c, dataContracts.h]
2023-09-13 add repeat reading of mask/filter after setting it.
2023-09-13 improve sensor worker shutdown logic when CAN coolant temp reading in error
    [sensorWorker.c]
2023-09-13 Do not increment sensors.errorCount on repeat out of range readings
    [sensorWorker.c]
2023-09-14 Add checksum to mask/filter setting
2023-09-14 fix mask/filter getting logic - request to get and response too fast
    [canBusWorker.c]
2023-09-14 tweak shutting down on coolant errors
    [dataContracts.h, sensorWorker.c]
2023-09-14 bump request error rate to 0.5
    [dataContracts.h]
2023-09-14 minor tweak to shutting down on coolant errors
    [sensorWorker.c]
2023-09-18 add CAN controller switch on/off to canBusWorker
2023-09-18 improve can error handling in sensorWorker
    [sensorWorker.c]
2023-09-19 fix flickering can sensor on ignition off
    [sensorWorker.c]
2023-09-19 fix bug in restartCanBus
    [canBusWorker.c]
2024-02-25 update xls file
    [SensorUnit_2023-05-28.xlsx]
2024-02-29 change CANBUS controller switch to go ON on HIGH
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2024-03-07 update SensorUnit
    [SensorUnit_2023-05-28.xlsx]
2024-03-08 remove sensorWorker wait on canBusWorker; other minor refactor
2024-03-09 update ui, SensorUnit
    [SensorUnit_2023-05-28.xlsx]
2024-03-09 fix sensorWorker usage of readAdc
    [sensorWorker.c]
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2024-03-09 fix adc reading
2024-03-09 add config.txt to boot folder
    [config.txt]
2024-03-09 make sure sensorWorker does not read can sensors if canbus not started
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2024-03-09 revert back to 2ms for canbus i2c request delay
    [canBusWorker.c]
2024-03-10 make canBusWorker set controller on/off pin mode only once
2024-03-10 increase wait time after request for filter, mask
2024-03-10 remove pin setting from config.txt
    [config.txt]
2024-03-10 decrease max coolant temp error count
    [sensorWorker.c]
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2024-03-10 lower wait time before restarting canbus from sensorworker
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2024-03-10 update canBusWorker to match the latest i2cCAN firmware
2024-03-13 bump lower rotor temp limit to 50 degC
2024-03-13 update SensorUnit xls
    [SensorUnit_2023-05-28.xlsx]
2024-03-13 revert change in min rotor temp
    [sensorProps.c]
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2024-04-30 updates to SensorUnit; design for trans pump
    [SensorUnit_2023-05-28.xlsx]
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2024-05-03 css fixes; add systemWorker to main
    [main.c]
2024-05-03 add trans pump ui status toggling to system worker
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2024-05-05 change trans pump GPIO to high for ON
2024-05-05 update to CANBUS start, make it wait for sensorWorker
2024-05-05 fix trans pump shutdown at app shutdown
    [systemWorker.c]
2024-05-05 set trans pump on temp to 95 c
2024-05-06 update SU xls
    [SensorUnit_2023-05-28.xlsx]
2024-07-14 set trans pump off temp to 50 degC
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2024-07-24 add buzzerToggleTimestamp; more cleanup
    [dataContracts.h, systemWorker.c]
2024-07-26 tweak buzzer chirp logic to use cycles instead of us
    [dataContracts.h, systemWorker.c]
2024-07-26 Update buzzer logic to go on for coolant and brake temps in alert
    [systemWorker.c]
2024-07-26 update buzzer logic so it does not run when ign off and rpm below threshold
    [systemWorker.c]
2025-06-21 Add PCB design for KnurCAN_V2
    [KnurCAN_V2-B_Cu.gbr, KnurCAN_V2-B_Mask.gbr, KnurCAN_V2-B_Paste.gbr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]
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2025-08-16 design file updates
    [KnurCAN_V2.kicad_pcb, KnurCAN_V2.kicad_sch]
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2025-08-16 shorten wait time after CAN on
    [canBusWorker.c]
2025-09-07 add missing readCanSensor call for IAT
    [dataContracts.h, sensorWorker.c]
2026-09-10 KnurCAN update to KiCAD 10
    [KnurCAN_V2.kicad_pcb]
2026-09-10 Never answer RaceChrono's filter with an ATT error
    Some dash readouts were live and some frozen in the car. The frozen ones were
    not a CAN, sensor or link fault: they were the frames that happened to sit
    behind an unknown packet ID in RaceChrono's subscription order.
    RaceChrono asks every DIY device for every packet ID it has a channel
    definition for, not only the ones that device publishes. Entering the logging
    regime it writes `deny all` and then one `allow single` per configured channel
    as a burst, and refusing one makes it abandon the rest - leaving everything
    behind the refusal with no notify source, the deny-all having already destroyed
    them all.
    The burst was captured on box 2 (Knur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
    [bluetoothWorker.c]
